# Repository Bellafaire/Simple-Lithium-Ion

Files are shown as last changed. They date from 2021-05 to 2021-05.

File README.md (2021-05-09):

# Simple Lithium Ion
A simple to use lithium ion boost, charge, and protection board designed to directly solder to standard 2.54mm perfboard for easier projects. For project logs and more in-depth information about the project please check out the project's hackaday.io page here: 
https://hackaday.io/project/167078-simple-lithium-ion

## Features
- On-board lithium ion charging 
- Over current protection
- Over/Under voltage protection
- 5V output from single battery cell

## License
MIT

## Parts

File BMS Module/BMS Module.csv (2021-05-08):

Source: | J:\Dropbox\Dropbox\Lab Projects\BMS Board\Rev3\BMS Module\BMS Module.sch
Date: | 12/21/2019 11:35:19 AM
Tool: | Eeschema (5.0.1)-3
Generator: | C:\Program Files\KiCad\bin\scripting\plugins/bom_csv_grouped_by_value.py
Component Count: | 34
Individual Components:
Item | Qty | Reference(s) | Value | LibPart | Footprint | Datasheet | Category | DK_Datasheet_Link | DK_Detail_Page | Description | Digi-Key_PN | Family | MPN | Manufacturer | Status | digikey
 |  | C1 | 47u | Device:C | Capacitor_SMD:C_1210_3225Metric | ~ |  |  |  |  |  |  |  |  |  | 1276-3064-1-ND
 |  | C2 | 47u | Device:C | Capacitor_SMD:C_1210_3225Metric | ~ |  |  |  |  |  |  |  |  |  | 1276-3064-1-ND
 |  | C3 | 47u | Device:C | Capacitor_SMD:C_1210_3225Metric | ~ |  |  |  |  |  |  |  |  |  | 1276-3064-1-ND
 |  | C4 | 47u | Device:C | Capacitor_SMD:C_1210_3225Metric | ~ |  |  |  |  |  |  |  |  |  | 1276-3064-1-ND
 |  | D1 | FSV340FP | Device:D_Schottky | Diode_SMD:D_SOD-123 | ~ |  |  |  |  |  |  |  |  |  | FSV340FPCT-ND
 |  | D2 | LED | Device:LED | LED_SMD:LED_0805_2012Metric_Castellated | ~
 |  | D3 | LED | Device:LED | LED_SMD:LED_0805_2012Metric_Castellated | ~
 |  | J1 | LARGE_PAD | Connector:Conn_01x01_Male | Custom Footprints:LARGE_PAD | ~
 |  | J2 | Conn_01x06_Male | Connector:Conn_01x06_Male | Connector_PinHeader_2.54mm:PinHeader_1x06_P2.54mm_Vertical | ~
 |  | J3 | LARGE_PAD | Connector:Conn_01x01_Male | Custom Footprints:LARGE_PAD | ~
 |  | J4 | USB_B_Micro | Connector:USB_B_Micro | digikey-footprints:USB_Micro_B_Female_10118192 | ~ |  |  |  |  |  |  |  |  |  | 609-4613-1-ND
 |  | J5 | AVR-ISP-6 | Connector:AVR-ISP-6 | Connector_PinHeader_2.54mm:PinHeader_2x03_P2.54mm_Vertical | ~
 |  | J6 | LARGE_PAD | Connector:Conn_01x01_Male | Custom Footprints:LARGE_PAD | ~
 |  | J7 | Conn_01x06_Male | Connector:Conn_01x06_Male | Connector_PinHeader_2.54mm:PinHeader_1x06_P2.54mm_Vertical | ~
 |  | J8 | LARGE_PAD | Connector:Conn_01x01_Male | Custom Footprints:LARGE_PAD | ~
 |  | L1 | 3.3u | Device:L | Custom Footprints:ASPI-0630HI-3R3N-T15 | ~ |  |  |  |  |  |  |  |  |  | ASPI-0630HI-3R3M-T15CT-ND
 |  | R1 | 10 | Device:R | Resistor_SMD:R_0805_2012Metric | ~
 |  | R2 | 3.3k | Device:R | Resistor_SMD:R_0805_2012Metric | ~
 |  | R3 | 1k | Device:R | Resistor_SMD:R_0805_2012Metric | ~
 |  | R4 | 50m | Device:R | Resistor_SMD:R_2512_6332Metric | ~ |  |  |  |  |  |  |  |  |  | YAG2156CT-ND
 |  | R5 | 2.2k | Device:R | Resistor_SMD:R_0805_2012Metric | ~
 |  | R6 | 10K | Device:R | Resistor_SMD:R_0805_2012Metric | ~
 |  | R7 | 0 | Device:R | Resistor_SMD:R_0805_2012Metric | ~ |  |  |  |  |  |  |  |  |  | RMCF0805ZT0R00CT-ND
 |  | R8 | 0 | Device:R | Resistor_SMD:R_0805_2012Metric | ~ |  |  |  |  |  |  |  |  |  | RMCF0805ZT0R00CT-ND
 |  | R9 | 470 | Device:R | Resistor_SMD:R_0805_2012Metric | ~ |  |  |  |  |  |  |  |  |  | A129745CT-ND
 |  | R10 | 470 | Device:R | Resistor_SMD:R_0805_2012Metric | ~ |  |  |  |  |  |  |  |  |  | A129745CT-ND
 |  | R11 | 10K | Device:R | Resistor_SMD:R_0805_2012Metric | ~
 |  | R12 | 220k | Device:R | Resistor_SMD:R_0805_2012Metric | ~
 |  | S1 | FSM4JSMATR | dk_Tactile-Switches:FSM4JSMATR | digikey-footprints:Switch_Tactile_SMD_6x6mm | https://www.te.com/commerce/DocumentDelivery/DDEController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 | Switches | https://www.te.com/commerce/DocumentDelivery/DDEController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 | /product-detail/en/te-connectivity-alcoswitch-switches/FSM4JSMATR/450-1759-1-ND/2271638 | SWITCH TACTILE SPST-NO 0.05A 24V | 450-1759-1-ND | Tactile Switches | FSM4JSMATR | TE Connectivity ALCOSWITCH Switches | Active | 450-1759-1-ND
 |  | U1 | ATtiny25-20MU | MCU_Microchip_ATtiny:ATtiny25-20MU | Package_DFN_QFN:QFN-20-1EP_4x4mm_P0.5mm_EP2.25x2.25mm | http://ww1.microchip.com/downloads/en/DeviceDoc/atmel-2586-avr-8-bit-microcontroller-attiny25-attiny45-attiny85_datasheet.pdf |  |  |  |  |  |  |  |  |  | 1611-ATTINY25V-15MTCT-ND
 |  | U2 | MCP73832T-2ACI_OT | dk_PMIC-Battery-Chargers:MCP73832T-2ACI_OT | digikey-footprints:SOT-753 | http://ww1.microchip.com/downloads/en/DeviceDoc/20001984g.pdf | Integrated Circuits (ICs) | http://ww1.microchip.com/downloads/en/DeviceDoc/20001984g.pdf | /product-detail/en/microchip-technology/MCP73832T-2ACI-OT/MCP73832T-2ACI-OTCT-ND/1979805 | IC LI-ION/LI-POLY CTRLR SOT23-5 | MCP73832T-2ACI/OTCT-ND | PMIC - Battery Chargers | MCP73832T-2ACI/OT | Microchip Technology | Active | MCP73832T-2ACI/OTCT-ND
 |  | U3 | MCP1650 | Regulator_Switching:MCP1650 | Package_SO:MSOP-8_3x3mm_P0.65mm | http://ww1.microchip.com/downloads/en/DeviceDoc/21876B.pdf |  |  |  |  |  |  |  |  |  | MCP1650S-E/MS-ND
 |  | U4 | STN3NF06L | BMS-Module-rescue:STN3NF06L-stn3nf06l | Package_TO_SOT_SMD:SOT-223 |  |  |  |  |  |  |  |  |  |  | 497-3177-1-ND
 |  | U5 | STN3NF06L | BMS-Module-rescue:STN3NF06L-stn3nf06l | Package_TO_SOT_SMD:SOT-223 |  |  |  |  |  |  |  |  |  |  | 497-3177-1-ND
Collated Components:
Item | Qty | Reference(s) | Value | LibPart | Footprint | Datasheet | Category | DK_Datasheet_Link | DK_Detail_Page | Description | Digi-Key_PN | Family | MPN | Manufacturer | Status | digikey
1 | 4 | C1, C2, C3, C4 | 47u | Device:C | Capacitor_SMD:C_1210_3225Metric | ~ |  |  |  |  |  |  |  |  |  | 1276-3064-1-ND
2 | 1 | D1 | FSV340FP | Device:D_Schottky | Diode_SMD:D_SOD-123 | ~ |  |  |  |  |  |  |  |  |  | FSV340FPCT-ND
3 | 2 | D2, D3 | LED | Device:LED | LED_SMD:LED_0805_2012Metric_Castellated | ~
4 | 4 | J1, J3, J6, J8 | LARGE_PAD | Connector:Conn_01x01_Male | Custom Footprints:LARGE_PAD | ~
5 | 2 | J2, J7 | Conn_01x06_Male | Connector:Conn_01x06_Male | Connector_PinHeader_2.54mm:PinHeader_1x06_P2.54mm_Vertical | ~
6 | 1 | J4 | USB_B_Micro | Connector:USB_B_Micro | digikey-footprints:USB_Micro_B_Female_10118192 | ~ |  |  |  |  |  |  |  |  |  | 609-4613-1-ND
7 | 1 | J5 | AVR-ISP-6 | Connector:AVR-ISP-6 | Connector_PinHeader_2.54mm:PinHeader_2x03_P2.54mm_Vertical | ~
8 | 1 | L1 | 3.3u | Device:L | Custom Footprints:ASPI-0630HI-3R3N-T15 | ~ |  |  |  |  |  |  |  |  |  | ASPI-0630HI-3R3M-T15CT-ND
9 | 1 | R1 | 10 | Device:R | Resistor_SMD:R_0805_2012Metric | ~
10 | 1 | R2 | 3.3k | Device:R | Resistor_SMD:R_0805_2012Metric | ~
11 | 1 | R3 | 1k | Device:R | Resistor_SMD:R_0805_2012Metric | ~
12 | 1 | R4 | 50m | Device:R | Resistor_SMD:R_2512_6332Metric | ~ |  |  |  |  |  |  |  |  |  | YAG2156CT-ND
13 | 1 | R5 | 2.2k | Device:R | Resistor_SMD:R_0805_2012Metric | ~
14 | 2 | R6, R11 | 10K | Device:R | Resistor_SMD:R_0805_2012Metric | ~
15 | 2 | R7, R8 | 0 | Device:R | Resistor_SMD:R_0805_2012Metric | ~ |  |  |  |  |  |  |  |  |  | RMCF0805ZT0R00CT-ND
16 | 2 | R9, R10 | 470 | Device:R | Resistor_SMD:R_0805_2012Metric | ~ |  |  |  |  |  |  |  |  |  | A129745CT-ND
17 | 1 | R12 | 220k | Device:R | Resistor_SMD:R_0805_2012Metric | ~
18 | 1 | S1 | FSM4JSMATR | dk_Tactile-Switches:FSM4JSMATR | digikey-footprints:Switch_Tactile_SMD_6x6mm | https://www.te.com/commerce/DocumentDelivery/DDEController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 | Switches | https://www.te.com/commerce/DocumentDelivery/DDEController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 | /product-detail/en/te-connectivity-alcoswitch-switches/FSM4JSMATR/450-1759-1-ND/2271638 | SWITCH TACTILE SPST-NO 0.05A 24V | 450-1759-1-ND | Tactile Switches | FSM4JSMATR | TE Connectivity ALCOSWITCH Switches | Active | 450-1759-1-ND
19 | 1 | U1 | ATtiny25-20MU | MCU_Microchip_ATtiny:ATtiny25-20MU | Package_DFN_QFN:QFN-20-1EP_4x4mm_P0.5mm_EP2.25x2.25mm | http://ww1.microchip.com/downloads/en/DeviceDoc/atmel-2586-avr-8-bit-microcontroller-attiny25-attiny45-attiny85_datasheet.pdf |  |  |  |  |  |  |  |  |  | 1611-ATTINY25V-15MTCT-ND
20 | 1 | U2 | MCP73832T-2ACI_OT | dk_PMIC-Battery-Chargers:MCP73832T-2ACI_OT | digikey-footprints:SOT-753 | http://ww1.microchip.com/downloads/en/DeviceDoc/20001984g.pdf | Integrated Circuits (ICs) | http://ww1.microchip.com/downloads/en/DeviceDoc/20001984g.pdf | /product-detail/en/microchip-technology/MCP73832T-2ACI-OT/MCP73832T-2ACI-OTCT-ND/1979805 | IC LI-ION/LI-POLY CTRLR SOT23-5 | MCP73832T-2ACI/OTCT-ND | PMIC - Battery Chargers | MCP73832T-2ACI/OT | Microchip Technology | Active | MCP73832T-2ACI/OTCT-ND
21 | 1 | U3 | MCP1650 | Regulator_Switching:MCP1650 | Package_SO:MSOP-8_3x3mm_P0.65mm | http://ww1.microchip.com/downloads/en/DeviceDoc/21876B.pdf |  |  |  |  |  |  |  |  |  | MCP1650S-E/MS-ND
22 | 2 | U4, U5 | STN3NF06L | BMS-Module-rescue:STN3NF06L-stn3nf06l | Package_TO_SOT_SMD:SOT-223 |  |  |  |  |  |  |  |  |  |  | 497-3177-1-ND

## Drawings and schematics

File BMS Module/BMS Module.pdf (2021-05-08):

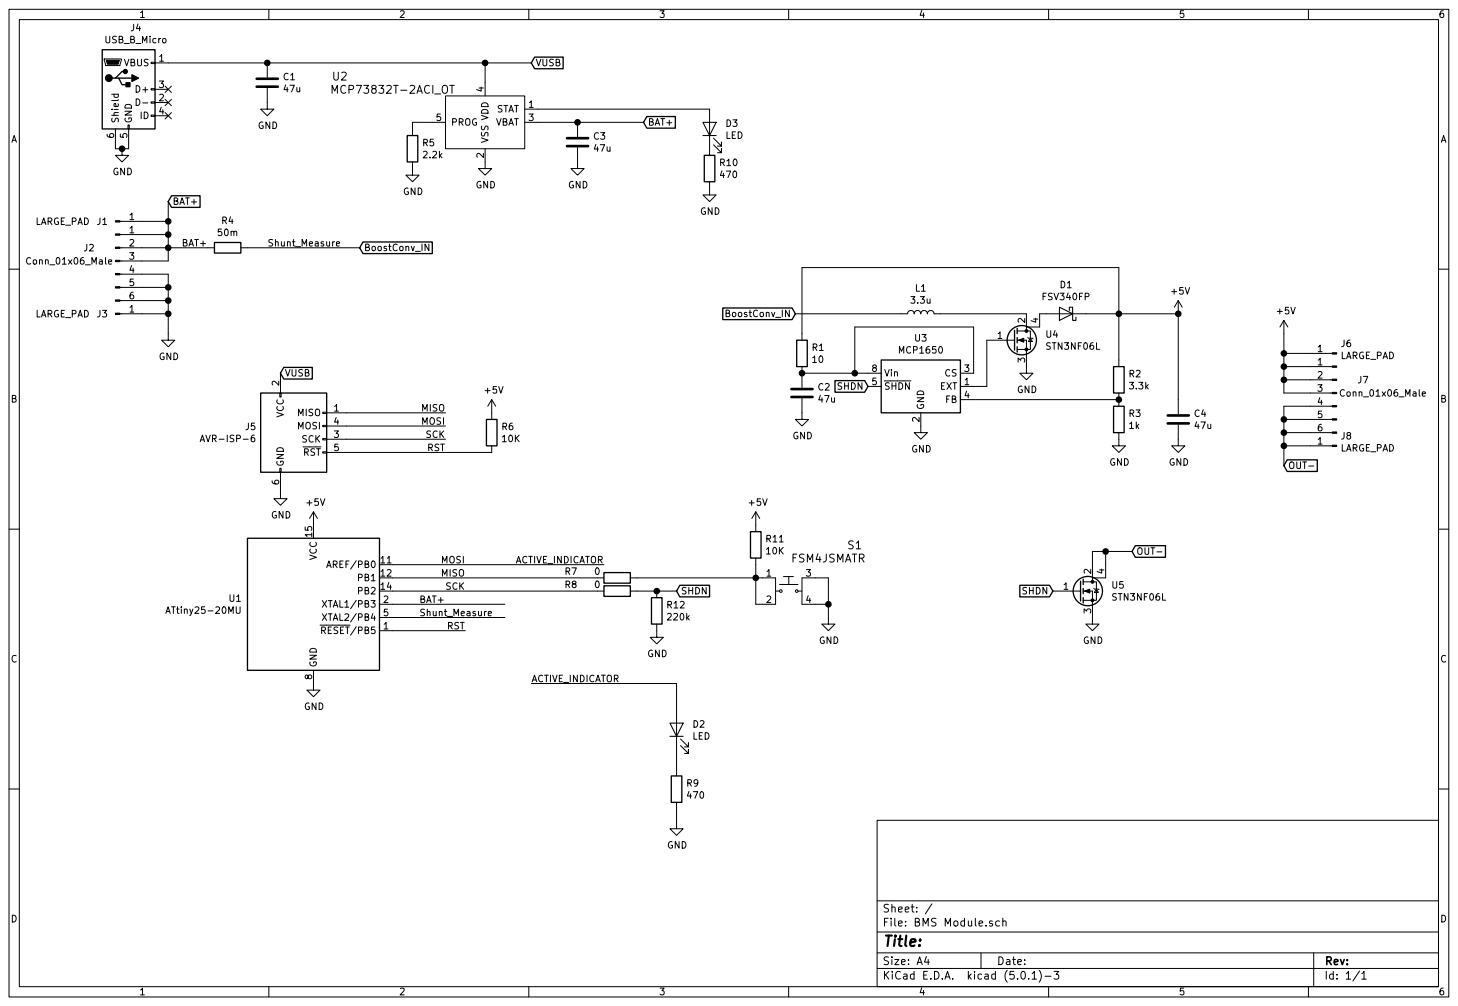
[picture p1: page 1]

2 CS 3 FB 4 SHDN 5 Vin 8 U3 MCP1650 BoostConv_IN

2 SCK 3 MOSI 4 RST 5 GND

4 U5STN3NF06L SHDN GND GND GND GND GND

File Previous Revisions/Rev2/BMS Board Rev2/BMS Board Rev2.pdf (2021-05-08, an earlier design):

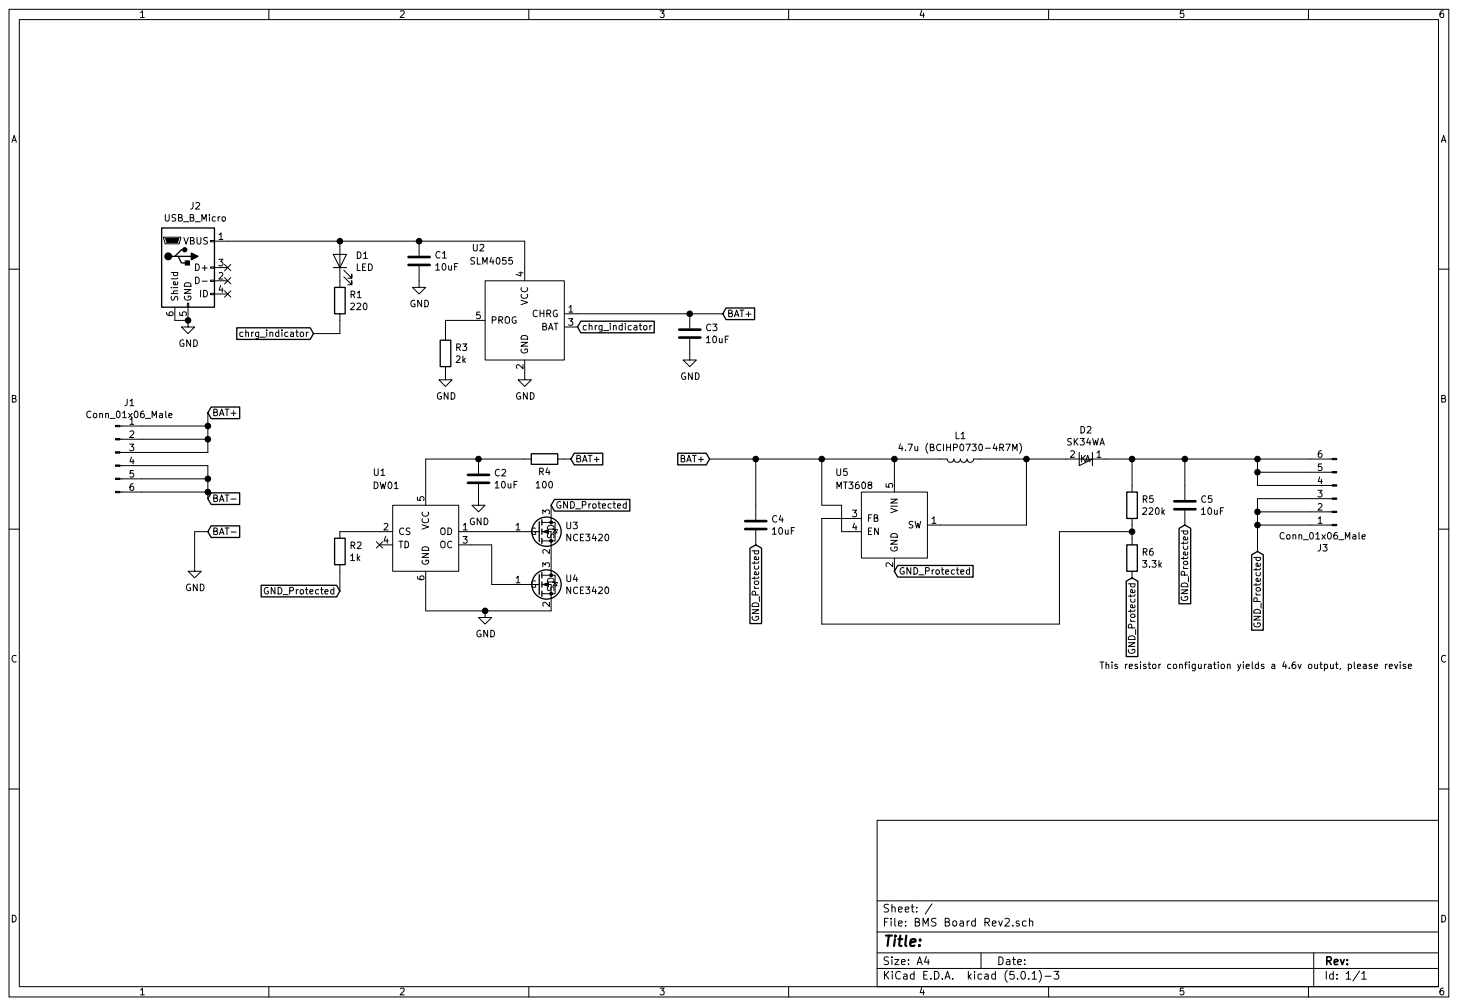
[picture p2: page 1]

This resistor configuration yields a 4.6v output, please revise

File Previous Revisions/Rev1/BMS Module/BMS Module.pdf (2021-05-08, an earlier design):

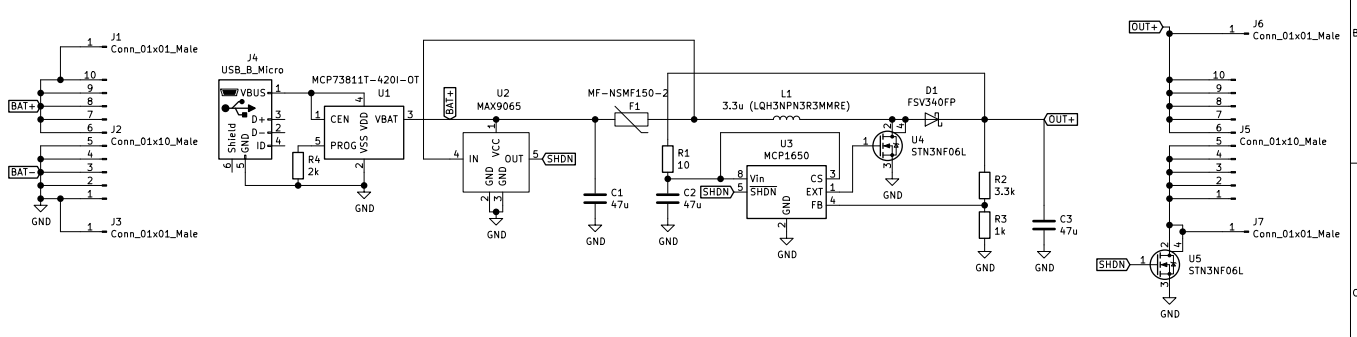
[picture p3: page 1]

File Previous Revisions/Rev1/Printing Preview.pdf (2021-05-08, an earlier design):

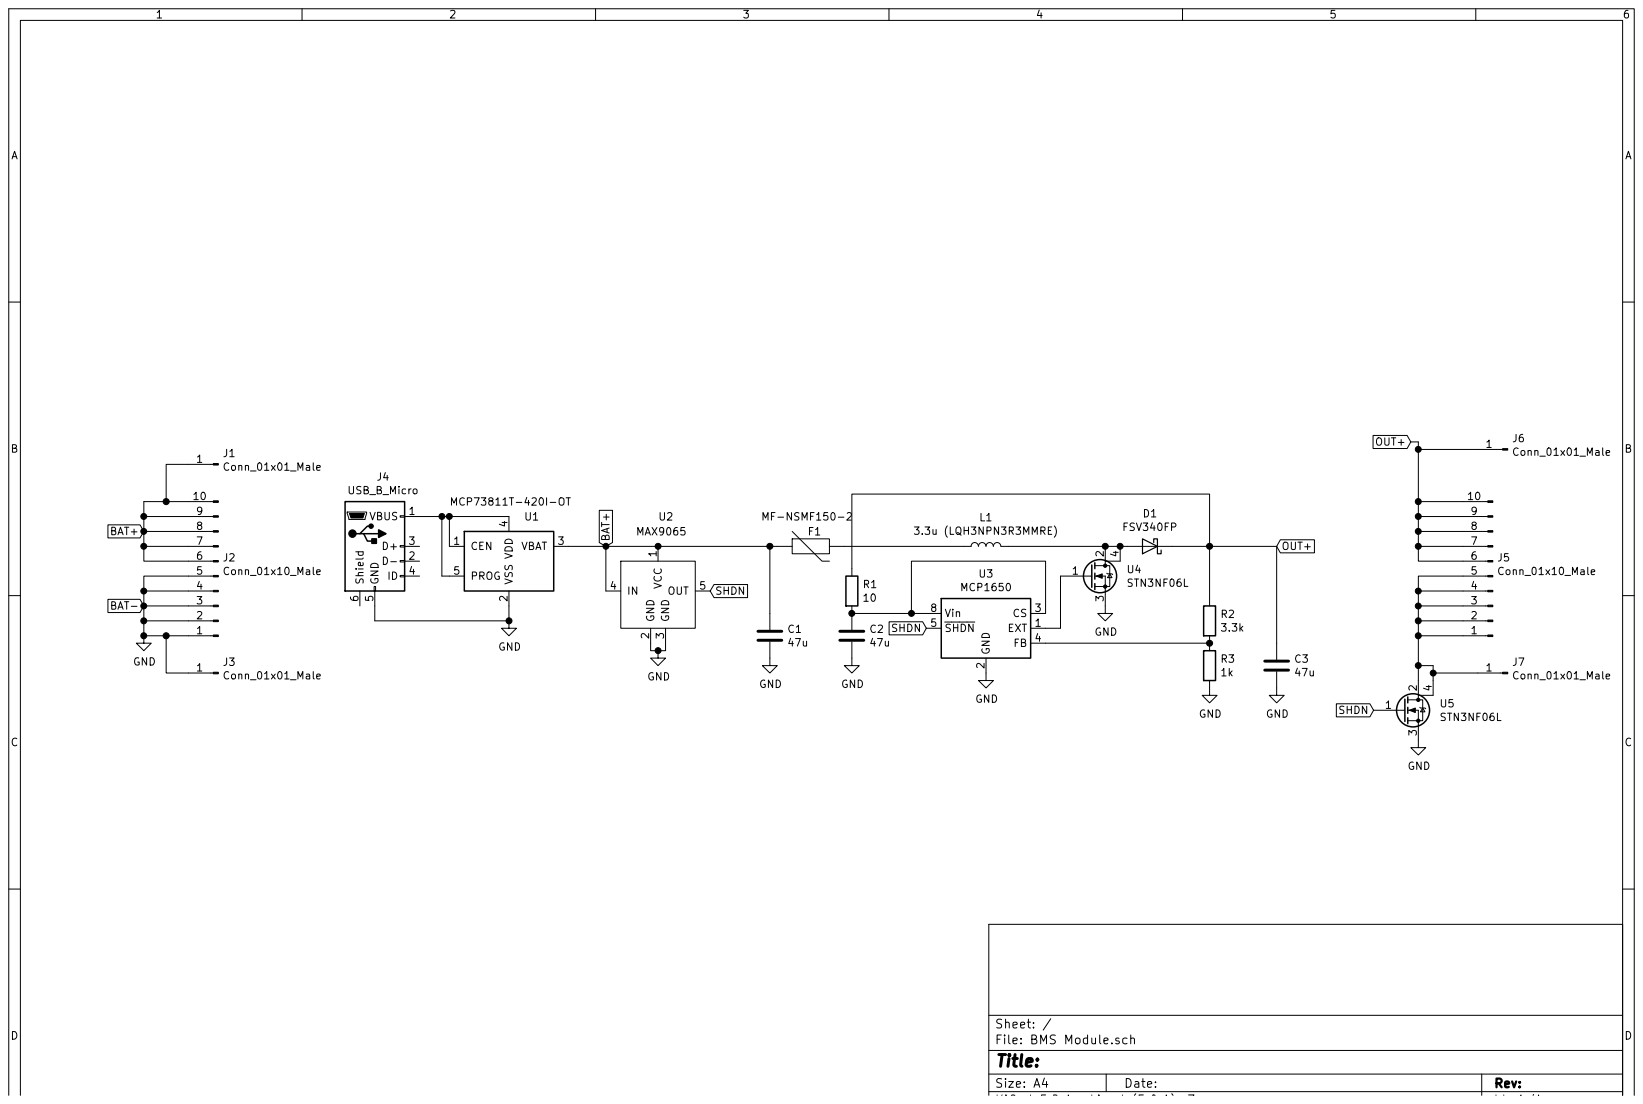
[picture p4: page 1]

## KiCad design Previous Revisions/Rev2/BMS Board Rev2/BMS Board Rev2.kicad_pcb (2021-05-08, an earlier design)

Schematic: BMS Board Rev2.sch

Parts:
C1, C2, C3, C4, C5: 10uF; C_0805_2012Metric
D1: LED; LED_0805_2012Metric
D2: SK34WA; D_SOD-123F
J1, J3: Conn_01x06_Male; PinHeader_1x06_P2.54mm_Vertical
J2: USB_B_Micro; USB_Micro-B_Molex_47346-0001
L1: 4.7u (BCIHP0730-4R7M); L_7x7x3
R1: 220; R_0805_2012Metric
R2: 1k; R_0805_2012Metric
R3: 2k; R_0805_2012Metric
R4: 100; R_0805_2012Metric
R5: 220k; R_0805_2012Metric
R6: 3.3k; R_0805_2012Metric
U1: DW01; SOT-23-6
U2: SLM4055; SOT-23-5
U3, U4: NCE3420; SOT-23
U5: MT3608; SOT-23-6

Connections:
BAT+: C3.1, C4.1, J1.1, J1.2, J1.3, L1.2, R4.2, U2.1, U5.4, U5.5
BAT-: C1.2, C2.2, C3.2, J1.4, J1.5, J1.6, J2.5 (GND), J2.6 (Shield), R3.2, U1.6, U2.2, U4.2
GND_Protected: C4.2, C5.2, J3.1, J3.2, J3.3, R2.2, R6.2, U3.3, U5.2
unnamed: C1.1, D1.2 (A), J2.1 (VBUS), U2.4
unnamed: C2.1, R4.1, U1.5
unnamed: C5.1, D2.1, J3.4, J3.5, J3.6, R5.1
unnamed: D1.1 (K), R1.1
unnamed: D2.2, L1.1, U5.1
unnamed: R2.1, U1.2
unnamed: R3.1, U2.5
unnamed: R5.2, R6.1, U5.3
unnamed: U1.1, U3.1
unnamed: U1.3, U4.1
unnamed: U3.2, U4.3
chrg_indicator: R1.2, U2.3

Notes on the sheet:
This resistor configuration yields a 4.6v output, please revise

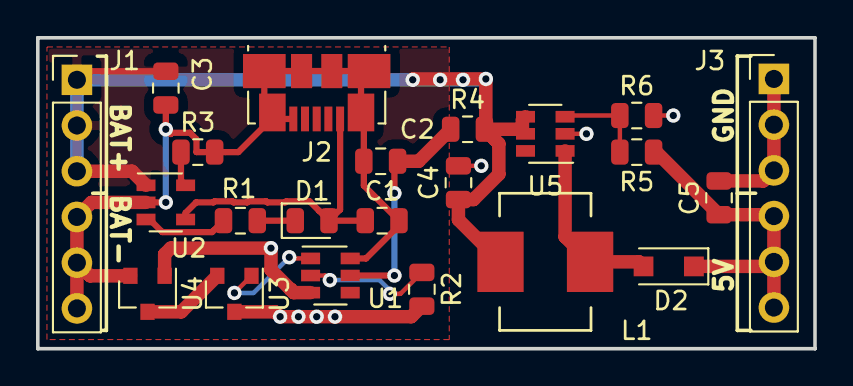
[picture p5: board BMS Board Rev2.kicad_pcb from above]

Board: 2 copper layers, 43.2 x 17.3 mm, 22 parts (0 on the bottom side), 15 nets.

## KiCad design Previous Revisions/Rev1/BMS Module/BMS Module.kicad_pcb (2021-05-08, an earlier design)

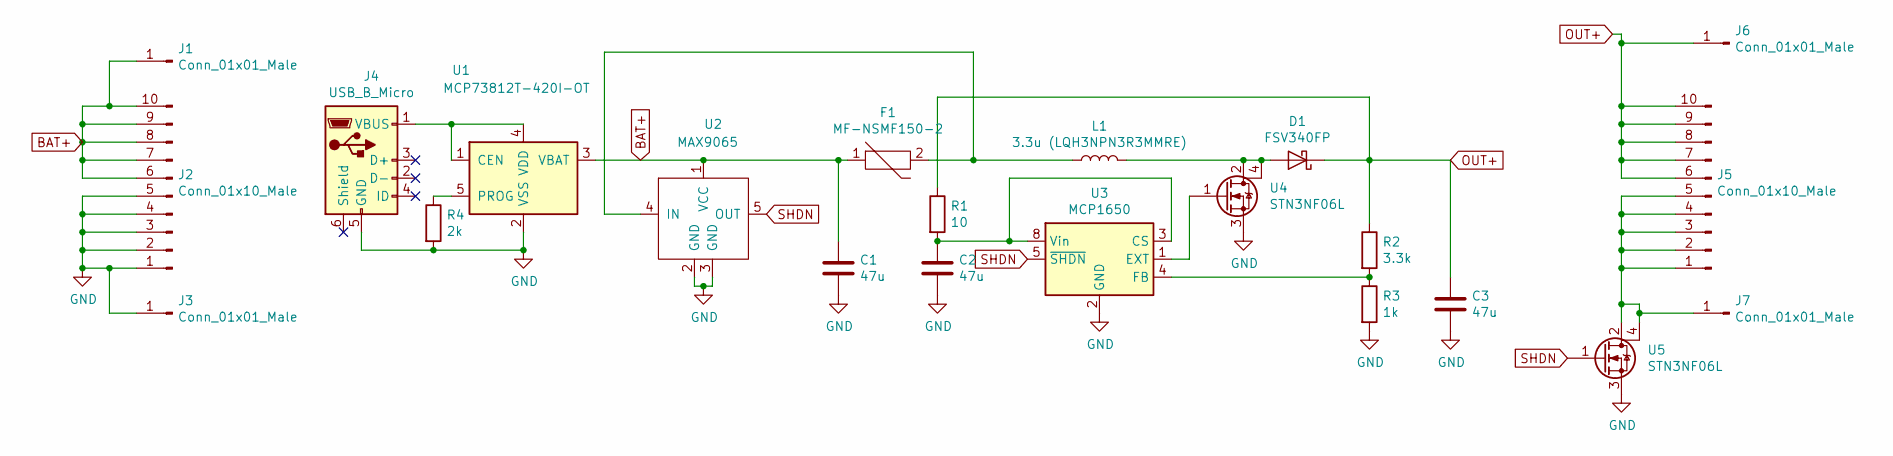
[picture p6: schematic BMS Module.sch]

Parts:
C1, C2, C3: 47u; C_1210_3225Metric
D1: FSV340FP; D_SOD-123
F1: MF-NSMF150-2; Fuse_1206_3216Metric
J1, J3, J6, J7: Conn_01x01_Male; PinHeader_1x01_P2.54mm_Vertical
J2, J5: Conn_01x10_Male; PinHeader_1x10_P2.54mm_Vertical
J4: USB_B_Micro; USB_Micro-B_GCT_USB3076-30-A
L1: 3.3u (LQH3NPN3R3MMRE); L_Taiyo-Yuden_MD-3030
R1: 10; R_0805_2012Metric
R2: 3.3k; R_0805_2012Metric
R3: 1k; R_0805_2012Metric
R4: 2k; R_0805_2012Metric
U1: MCP73812T-420I-OT; SOT-23-5
U2: MAX9065; SOT-23-5
U3: MCP1650; MSOP-8_3x3mm_P0.65mm
U4, U5: STN3NF06L; SOT-223

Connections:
BAT+: C1.1, F1.1, J1.1, J2.6, J2.7, J2.8, J2.9, J2.10, U1.3 (VBAT), U2.1 (VCC)
GND: C1.2, C2.2, C3.2, J2.1, J2.2, J2.3, J2.4, J2.5, J3.1, J4.5 (GND), R3.2, R4.2, U1.2 (VSS), U2.2 (GND), U2.3 (GND), U3.2 (GND), U4.3, U5.3
unnamed: C2.1, R1.2, U3.3 (CS), U3.8 (Vin)
unnamed: D1.2 (A), L1.2, U4.2, U4.4
unnamed: F1.2, L1.1, U2.4 (IN)
unnamed: J4.1 (VBUS), U1.1 (CEN), U1.4 (VDD)
unnamed: J5.1, J5.2, J5.3, J5.4, J5.5, J7.1, U5.2, U5.4
unnamed: R2.2, R3.1, U3.4 (FB)
unnamed: R4.1, U1.5 (PROG)
unnamed: U3.1 (EXT), U4.1
OUT+: C3.1, D1.1 (K), J5.6, J5.7, J5.8, J5.9, J5.10, J6.1, R1.1, R2.1
SHDN: U2.5 (OUT), U3.5 (~SHDN), U5.1

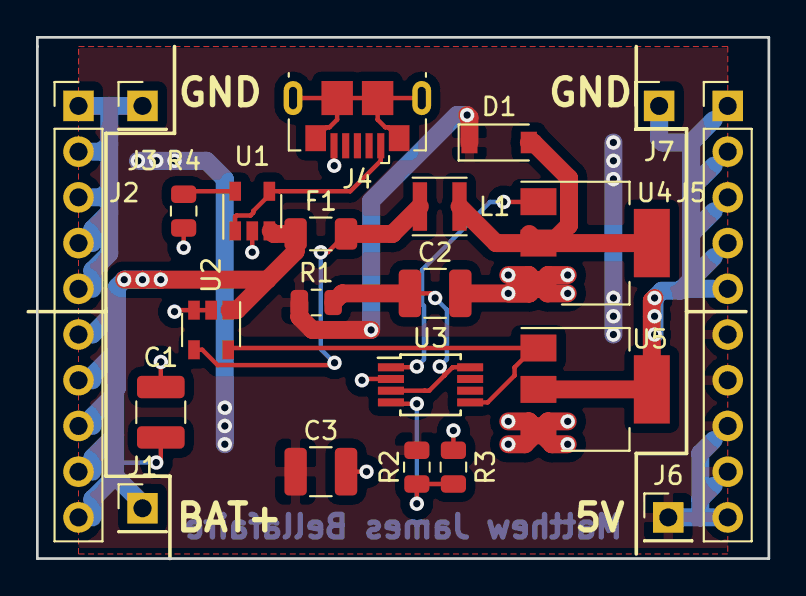
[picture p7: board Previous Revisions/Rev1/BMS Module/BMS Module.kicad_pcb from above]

Board: 2 copper layers, 40.6 x 29.0 mm, 22 parts (0 on the bottom side), 12 nets.

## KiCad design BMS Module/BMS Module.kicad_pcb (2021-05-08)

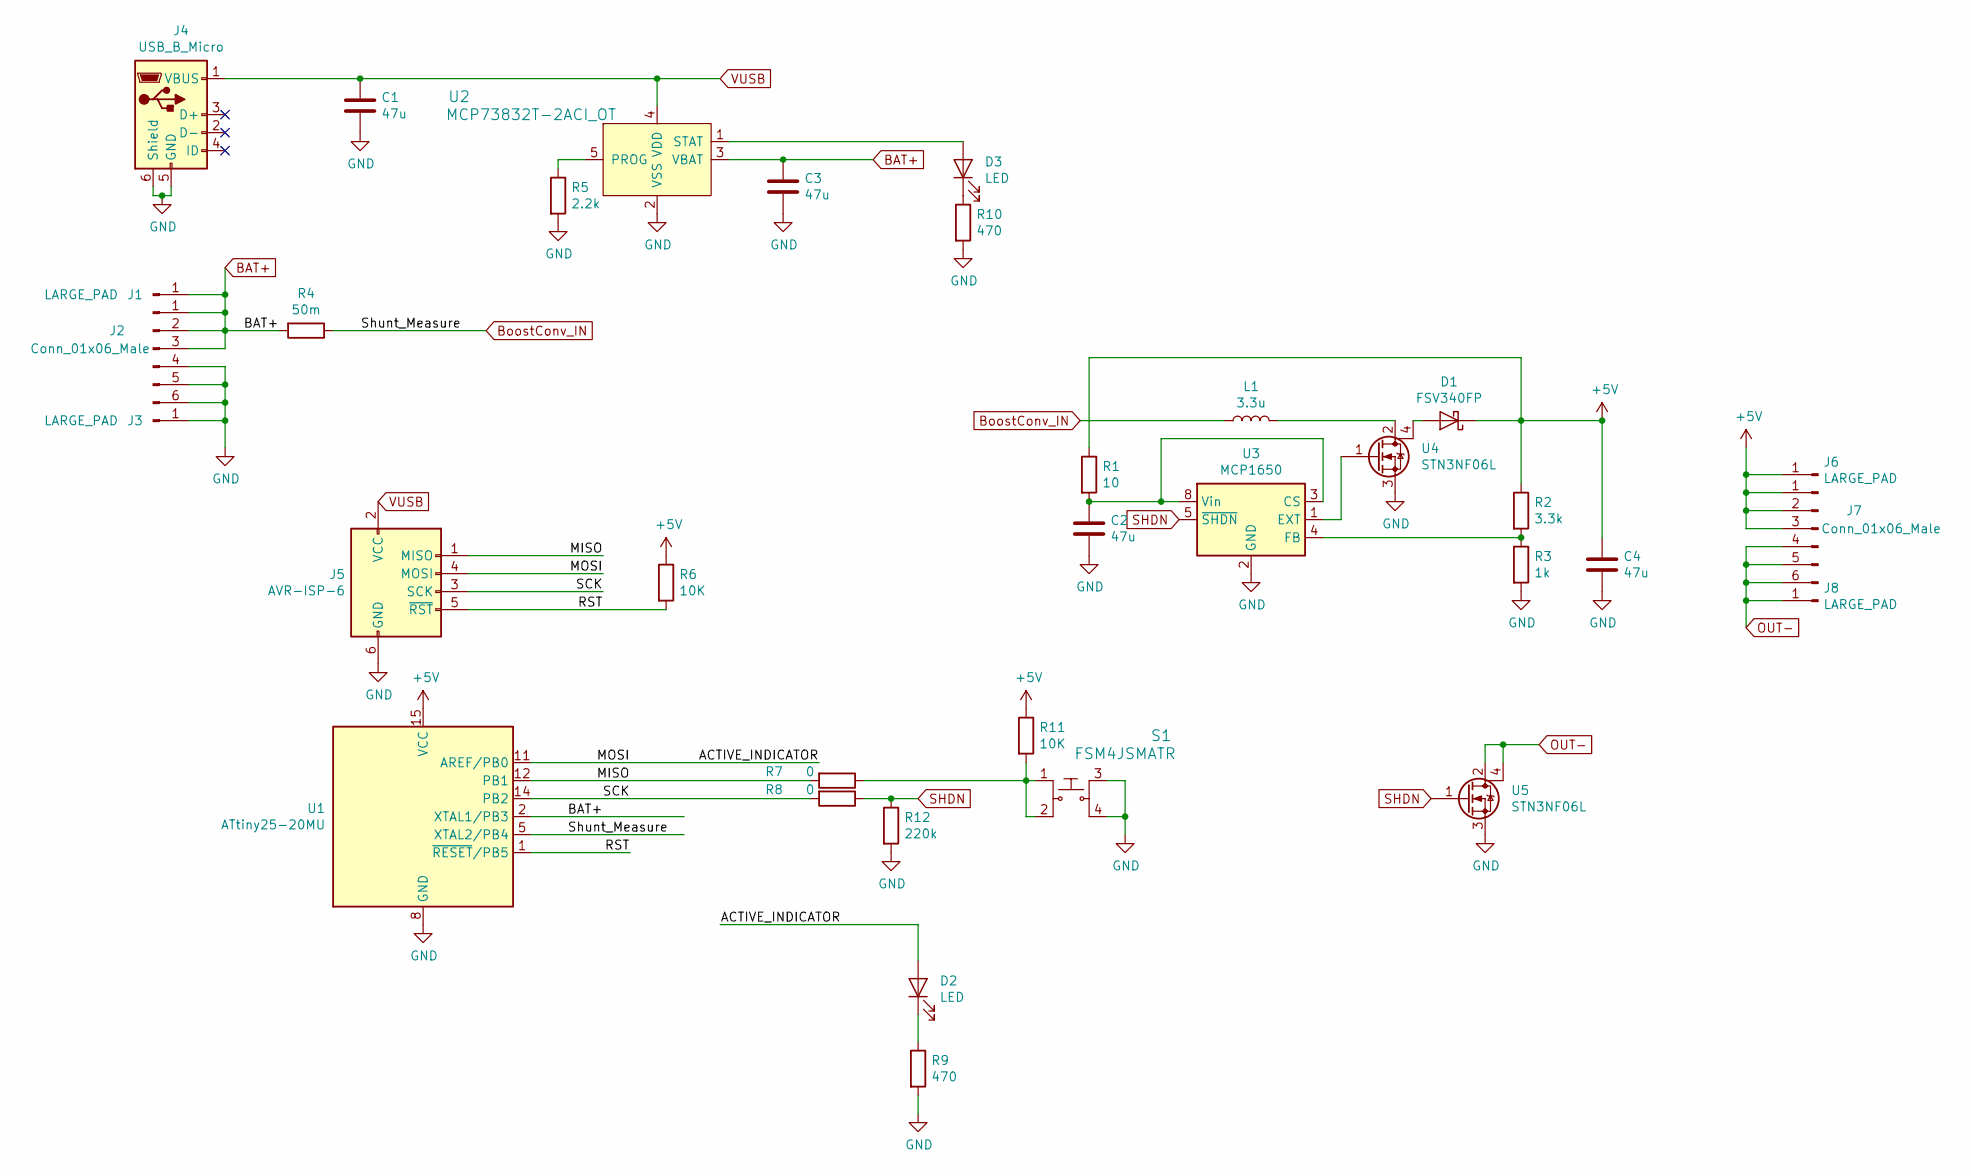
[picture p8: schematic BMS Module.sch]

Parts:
C1, C2, C3, C4: 47u; C_1210_3225Metric; digikey 1276-3064-1-ND
D1: FSV340FP; D_SOD-123; digikey FSV340FPCT-ND
D2, D3: LED; LED_0805_2012Metric_Castellated
J1, J3, J6, J8: LARGE_PAD
J2, J7: Conn_01x06_Male; PinHeader_1x06_P2.54mm_Vertical
J4: USB_B_Micro; USB_Micro_B_Female_10118192; digikey 609-4613-1-ND
J5: AVR-ISP-6; PinHeader_2x03_P2.54mm_Vertical
L1: 3.3u; ASPI-0630HI-3R3N-T15; digikey ASPI-0630HI-3R3M-T15CT-ND
R1: 10; R_0805_2012Metric
R2: 3.3k; R_0805_2012Metric
R3: 1k; R_0805_2012Metric
R4: 50m; R_2512_6332Metric; digikey YAG2156CT-ND
R5: 2.2k; R_0805_2012Metric
R6, R11: 10K; R_0805_2012Metric
R7, R8: 0; R_0805_2012Metric; digikey RMCF0805ZT0R00CT-ND
R9, R10: 470; R_0805_2012Metric; digikey A129745CT-ND
R12: 220k; R_0805_2012Metric
S1: FSM4JSMATR; Switch_Tactile_SMD_6x6mm; MPN FSM4JSMATR; digikey 450-1759-1-ND
U1: ATtiny25-20MU; QFN-20-1EP_4x4mm_P0.5mm_EP2.25x2.25mm; digikey 1611-ATTINY25V-15MTCT-ND
U2: MCP73832T-2ACI_OT; SOT-753; MPN MCP73832T-2ACI/OT; digikey MCP73832T-2ACI/OTCT-ND
U3: MCP1650; MSOP-8_3x3mm_P0.65mm; digikey MCP1650S-E/MS-ND
U4, U5: STN3NF06L; SOT-223; digikey 497-3177-1-ND

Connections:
+5V: C4.1, D1.1 (K), J6.1, J7.1, J7.2, J7.3, R1.1, R2.1, R6.1, R11.1, U1.15 (VCC)
/ACTIVE_INDICATOR: D2.2 (A), J5.4 (MOSI), U1.11 (AREF/PB0)
/MISO: J5.1 (MISO), R7.2, U1.12 (PB1)
/RST: J5.5 (~RST), R6.2, U1.1 (~RESET~/PB5)
/SCK: J5.3 (SCK), R8.2, U1.14 (PB2)
BAT+: C3.1, J1.1, J2.1, J2.2, J2.3, R4.2, U1.2 (XTAL1/PB3), U2.3 (VBAT)
BoostConv_IN: L1.1, R4.1, U1.5 (XTAL2/PB4)
GND: C1.2, C2.2, C3.2, C4.2, J2.4, J2.5, J2.6, J3.1, J4.5 (GND), J4.6 (Shield), J5.6 (GND), R3.2, R5.2, R9.2, R10.2, R12.2, S1.3, S1.4, U1.8 (GND), U1.21 (GND), U2.2 (VSS), U3.2 (GND), U4.3, U5.3
unnamed: C2.1, R1.2, U3.3 (CS), U3.8 (Vin)
unnamed: D1.2 (A), U4.4
unnamed: D2.1 (K), R9.1
unnamed: D3.1 (K), R10.1
unnamed: D3.2 (A), U2.1 (STAT)
unnamed: L1.2, U4.2
unnamed: R2.2, R3.1, U3.4 (FB)
unnamed: R5.1, U2.5 (PROG)
unnamed: R7.1, R11.2, S1.1, S1.2
unnamed: U3.1 (EXT), U4.1
OUT-: J7.4, J7.5, J7.6, J8.1, U5.2, U5.4
SHDN: R8.1, R12.1, U3.5 (~SHDN), U5.1
VUSB: C1.1, J4.1 (VBUS), J5.2 (VCC), U2.4 (VDD)

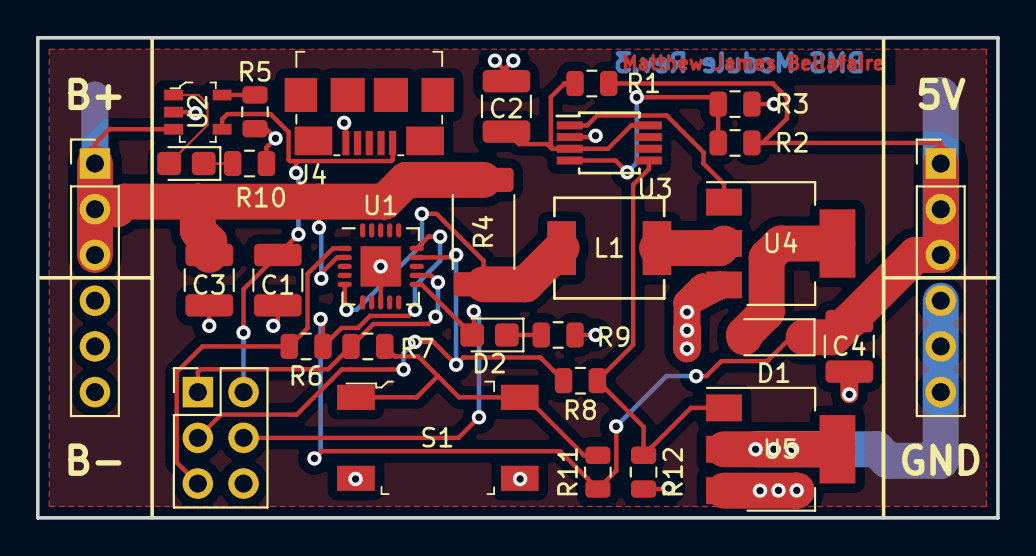
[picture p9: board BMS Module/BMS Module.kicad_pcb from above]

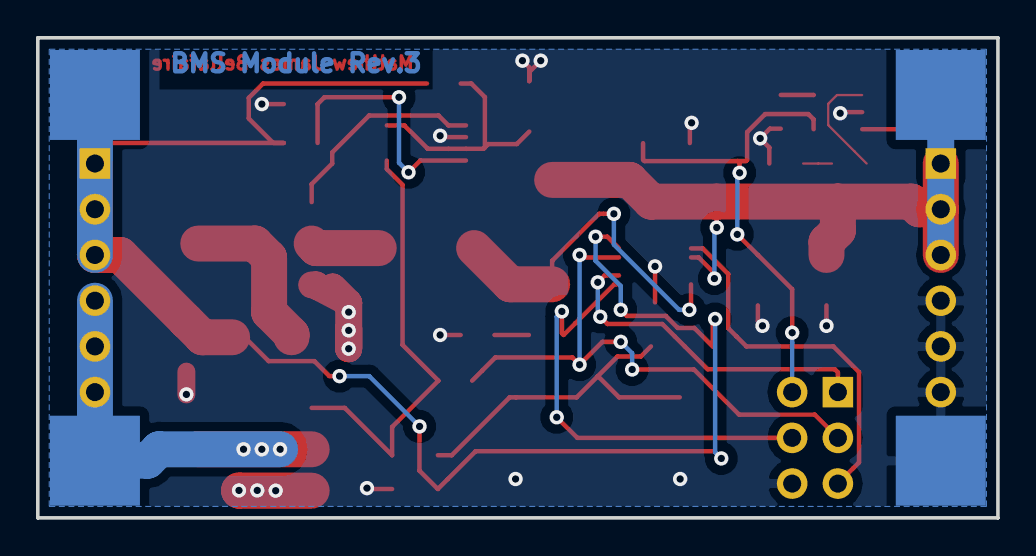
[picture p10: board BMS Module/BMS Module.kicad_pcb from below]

Board: 2 copper layers, 53.3 x 26.7 mm, 34 parts (4 on the bottom side), 21 nets.

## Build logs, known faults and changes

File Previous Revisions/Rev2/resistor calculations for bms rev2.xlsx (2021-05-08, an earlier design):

R1 | R2 | Vout | Available Resistors | R1 | R2 | VOUT
33000 | 4700 | 4.812765957 | 10 | 330000 | 10 | 19800.6
 |  |  | 100 | 220000 | 10 | 13200.6
R1 | R2 | Vout | 1000 | 100000 | 10 | 6000.6
330000 | 100000 | 2.58 | 2200 | 330000 | 100 | 1980.6
 |  |  | 3300 | 22000 | 10 | 1320.6
 |  |  | 4700 | 220000 | 100 | 1320.6
 |  |  | 22000 | 100000 | 100 | 600.6
 |  |  | 100000 | 4700 | 10 | 282.6
 |  |  | 220000 | 3300 | 10 | 198.6
 |  |  | 330000 | 330000 | 1000 | 198.6
 |  |  |  | 2200 | 10 | 132.6
 |  |  |  | 22000 | 100 | 132.6
 |  |  |  | 220000 | 1000 | 132.6
 |  |  |  | 330000 | 2200 | 90.6
 |  |  |  | 1000 | 10 | 60.6
 |  |  |  | 100000 | 1000 | 60.6
 |  |  |  | 220000 | 2200 | 60.6
 |  |  |  | 330000 | 3300 | 60.6
 |  |  |  | 330000 | 4700 | 42.72765957
 |  |  |  | 220000 | 3300 | 40.6
 |  |  |  | 4700 | 100 | 28.8
 |  |  |  | 220000 | 4700 | 28.68510638
 |  |  |  | 100000 | 2200 | 27.87272727
 |  |  |  | 3300 | 100 | 20.4
 |  |  |  | 100000 | 3300 | 18.78181818
 |  |  |  | 2200 | 100 | 13.8
 |  |  |  | 22000 | 1000 | 13.8
 |  |  |  | 100000 | 4700 | 13.36595745
 |  |  |  | 330000 | 22000 | 9.6
 |  |  |  | 100 | 10 | 6.6
 |  |  |  | 1000 | 100 | 6.6
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

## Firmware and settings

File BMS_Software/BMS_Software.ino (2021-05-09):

#include <BatteryMonitor.h>
#define F_CPU 8000000
#include <util/delay.h> //using the arduino delay takes more flash than the util/delay.h hence why we use it instead. Actually saved about 100 bytes by doing this
#include <avr/sleep.h>
#include <avr/interrupt.h>

//be sure to enable Brown out detection at 2.7V
//core clock should be 1MHz to reduce power consumption.

#define ACTIVE_IND PB0
#define BUTTON PB1
#define SHDN PB2
#define BAT_POS 3          //ADC3
#define CURRENT_MEASURE 2  //ADC4

#define OVER_CURRENT_LIMIT 1.0
#define UNDER_VOLTAGE_THRESHOLD 3.0
#define ABSOLUTE_MINIMUM_VOLTAGE 2.7

#define BUTTON_HOLD_TO_SLEEP_MS 500
#define LOOP_DELAY 10

#define SLEEP_BUTTON_COUNT BUTTON_HOLD_TO_SLEEP_MS / LOOP_DELAY

int buttonHeldCounter = 0;

BatteryMonitor bat = BatteryMonitor(BAT_POS, CURRENT_MEASURE);

//disable sleep mode upon wakeup.
ISR (PCINT0_vect)
{
  //if the button is pressed then wakeup. pinchange on release doesn't count
    if (!(PINB & (1 << BUTTON))) {
      MCUCR &= ~(1 << SE);  //Disabling sleep mode inside interrupt routine
    }
}

void setup() {
  DDRB |= (1 << ACTIVE_IND) | (1 << SHDN);
  bat.setCurrentSenseResistance(0.05);

  //check if device has browned out.
  //if so there must have been an over current condition
  if (MCUSR & 0x04) {
    brownOutDetected();
  }

  //enable pinchange interrupt on button pin
  sei();
  GIMSK |= (1 << PCIE);
  PCMSK = (1 << PCINT1);
  set_sleep_mode(SLEEP_MODE_PWR_DOWN);

  //now that the check is complete we can activate the output ports
  PORTB = (1 << SHDN) | (1 << ACTIVE_IND);

}


void brownOutDetected() {
  PORTB &= ~((1 << SHDN) | (1 << ACTIVE_IND));
  while (1) {
    if (!(PINB & (1 << BUTTON))) {
      PORTB = (1 << SHDN) | (1 << ACTIVE_IND);
      MCUSR &= ~0x04; //clear brownout detection.
      return;
    }
    PORTB ^= (1 << ACTIVE_IND);
    _delay_ms(100);
  }
}


void overCurrentShutdown() {
  PORTB &= ~((1 << SHDN) | (1 << ACTIVE_IND));
  while (1) {
    for (int a = 0; a < 10; a++) {
      if (!(PINB & (1 << BUTTON))) {
        PORTB = (1 << SHDN) | (1 << ACTIVE_IND);
        return;
      }
      PORTB ^= (1 << ACTIVE_IND);
      _delay_ms(10);
    }
    _delay_ms(50);
  }
}

void lowVoltageShutdown() {
  PORTB &= ~(1 << SHDN);
  while (1) {
    if (!(PINB & (1 << BUTTON))) {
      PORTB = (1 << SHDN) | (1 << ACTIVE_IND);
      return;
    }
    PORTB ^= (1 << ACTIVE_IND);
    _delay_ms(25);
  }
}

void loop() {
  if (readBatMultiple(10) > UNDER_VOLTAGE_THRESHOLD) {
    if (readCurrentMultiple(10) < OVER_CURRENT_LIMIT) {
      PORTB = (1 << SHDN) | (1 << ACTIVE_IND);
    } else {
      overCurrentShutdown();
    }
  } else {
    lowVoltageShutdown();
  }

  if (!(PINB & (1 << BUTTON))) {
    rapidBlink();
    PORTB &= ~((1 << SHDN) | (1 << ACTIVE_IND));
    sleep_enable();
    set_sleep_mode(SLEEP_MODE_PWR_DOWN);
    sleep_cpu();
  }
}


void rapidBlink() {
  for (int a = 0; a < 6; a++) {
    PORTB ^= (1 << ACTIVE_IND);
    _delay_ms(10);
  }
}


float readCurrentMultiple(int reads) {
  float total = 0;
  for (int a = 0; a < reads; a++) {
    total += bat.getBatteryCurrent();
  }
  return total / reads;
}

float readBatMultiple(int reads) {
  float total = 0;
  for (int a = 0; a < reads; a++) {
    total += bat.getCurrentBatteryVoltage();
  }
  return total / reads;
}

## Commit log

2021-05-08 Commit of all revision 3 files from project
    [BMS Module-B.Cu.gbr, BMS Module-B.Mask.gbr, BMS Module-B.Paste.gbr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]
2021-05-08 Commit of files from previous revisions
    [BMS Board Rev2-B.Cu.gbr, BMS Board Rev2-B.Mask.gbr, BMS Board Rev2-B.Paste.gbr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]
2021-05-09 added brown out detection, device can now also be put into sleep mode by holding button.
    [BMS_Software.ino]
2021-05-09 corrected pin declarations
